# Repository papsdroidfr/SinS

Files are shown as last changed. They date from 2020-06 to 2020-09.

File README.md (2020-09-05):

# SinS
Dans le cadre du concours du #ChallengeDesMakers2020, notre équipe #OuiAreSins composée de François de https://www.framboise314.fr/, Frédéric de https://garatronic.fr/index.php/fr/, Dominique de https://shop.mchobby.be/fr/ et moi même Olivier de https://www.papsdroid.fr/ nous réalisons un jeux de mémoire visuelle et auditive à base d'une PYBStick26, mais ne vous y trompez pas:  Sins Is Not Simon !

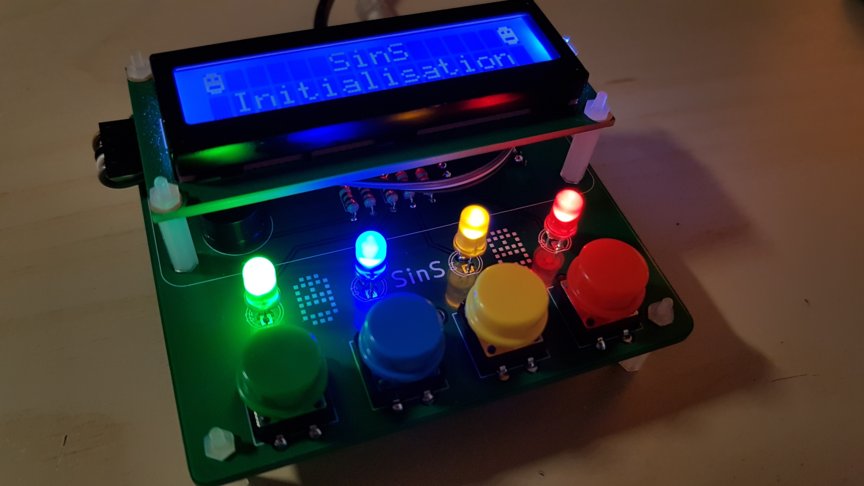
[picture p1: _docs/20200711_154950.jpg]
carte PCB


Il faut retrouver les clés de 10 coffres à trésors cachés dans un immense labyrinthe.

Dans chaque pièce où vous entrez, il y a 4 sorties de 4 couleurs distinctes. Vous avez un guide qui ouvre le chemin et vous montre les  3 prochaines portes à ouvrir pour trouver une première clé. Si vous réussissez, votre guide vous montre alors les 3 portes suivantes à ouvrir y compris les 3 premières déjà empruntées, et ainsi de suite... Le jeux se termine quand vous avez rapporté les 10 clés, ou bien quand vous vous trompez et êtes perdu dans le labyrinthe.

Vous pouvez jouer à plusieurs pour trouver les 10 clés: organisez votre équipe pour retenir le bon ordre d'ouverture des portes.

## matériel nécessaire
* 1 PYBStick26 avec ses deux barettes femelles 13pins soudées.
* 4 leds 5mm (Verte, Bleue, Jaune, Rouge)
* 4 résistances 220 ohms (pour les leds)
* 1 résistance 330 ohms (pour le buzzer), sinon 220 ohms sera aussi valable.
* 1 diode de redressement 1N4148 (optionel, le prototype fonctionne sans: c'est une diode de roue libre pour protéger le buzzer)
* 1 petit buzzer passif (attention à bien prendre un passif)
* 4 boutons poussoirs (6mm pour une breadboard, ou 12mm avec capuchons colorés ronds vert, bleu, jaune et rouge pour le circuit imprimé)
* 1 écran LCD 1602 avec backpack I2C
* 1 nappe souple femelle/femelle 4 pins, pour connecter le LCD au circuit.
* 1 connecteur pin header coudé 4 pins mâles 2.54mm, pour relier le LCD (impéartivement coudé pour le circuit imprimé)

Si vous comptez souder les composants sur le circuit imprimé proposé:
* 1 circuit imprimé, à faire fabriquer à partir des fichier GERBER_SINS.zip fournis.
* 1 alimentation 5V DC avec Jack femelle, 1A est suffisant 
* 1 diode Shotky SB560 (elle protège l'alimentation externe 5V quand l'USB est connectée)
* 1 connecteur Barrel JackDC mâle, 3 points de soudure
* 2 pin header mâle 13 pins 2.54mm à souder (pour y connecter la PYBStick)
* quelques entretoises M2.5 (ou M2 aussi ça passera): 8*M/F 15mm + 6 écrous + 2 vis

Le lien avec le tutoriel de montage sera bientôt ajouté sur ce dépôt.

## boîtier imprimé 3D 

François nous a réalisé un boîtier sur mesure à imprimer en 3D.
Le [lien avec les sources](https://ouiaremakers.com/posts/tutoriel-diy-un-boitier-en-impression-3d-pour-le-projet-ouiaresins)

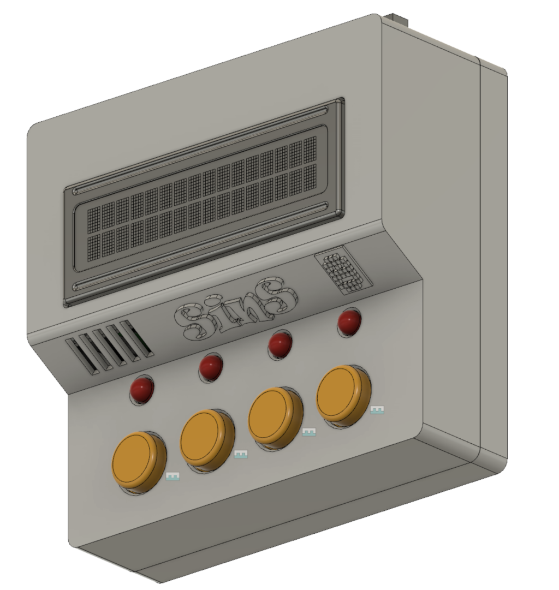
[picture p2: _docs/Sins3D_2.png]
boiter3D


## prototypage sur breadboard

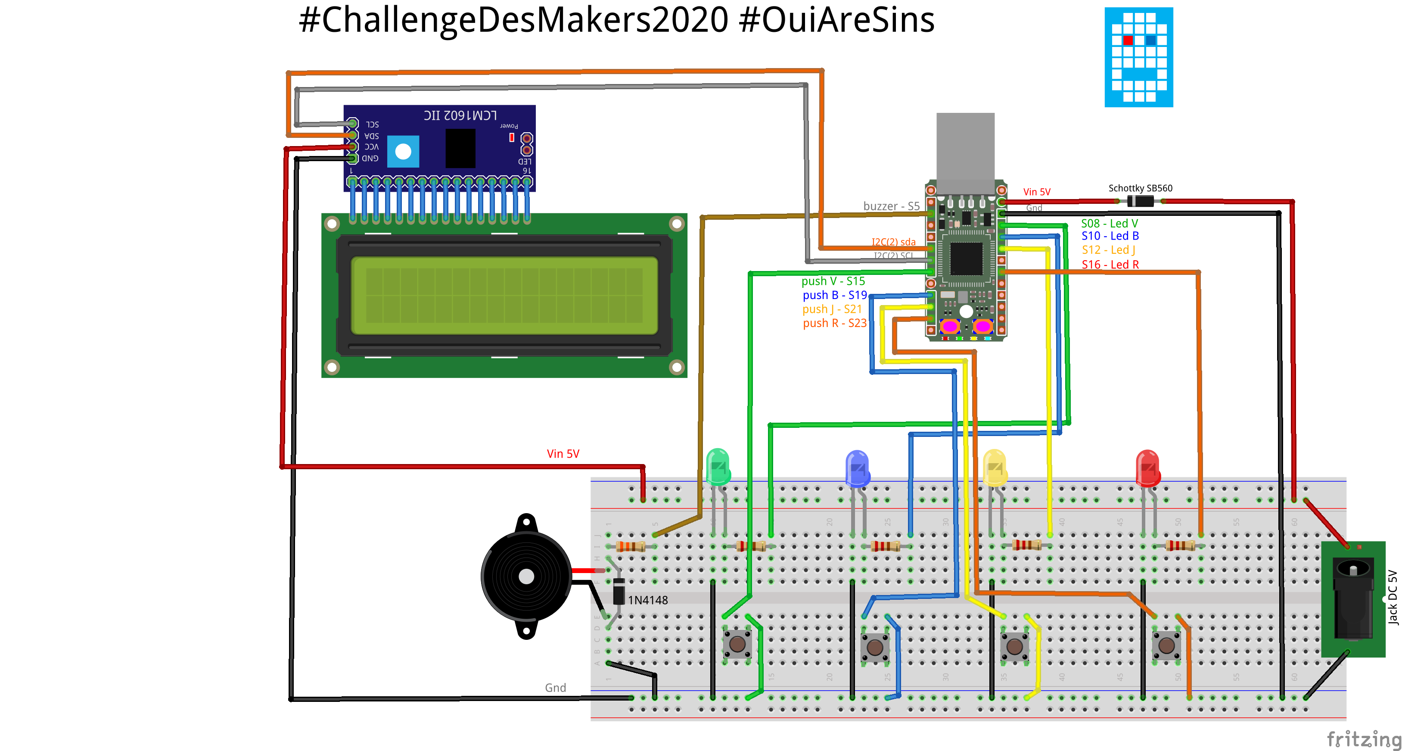
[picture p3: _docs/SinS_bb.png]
prototype breadbaord


## scripts micropython à installer sur la PYBStick
Dans le répertoire PYBFLASH qui s'affiche à l'ordinateur lors du branchement de la PYBStick26 sur un port USB, déposez tous les fichiers Micropython ci-dessous:
* buttons.py : gestion du rack de boutons poussoirs
* buzzer.py  : gestion du buzzer
* lcd.py     : gestion du LCD
* lcd2ic.py  : conçu par [MC Hobby](https://github.com/mchobby/pyboard-driver/tree/master/PYBStick): gestion du LCD via I2C de la PYBStick
* leds.py    : gestion du rack de leds
* main.py    : script principaldu jeux
* pwm.py     : conçu par [MC Hobby](https://github.com/mchobby/pyboard-driver/tree/master/PYBStick) : gestion des sorties PWM de la PYBStick

## synoptique du jeux
Un message d'accueil avec musique apparait, ainsi qu'une petite animation colorée des leds.

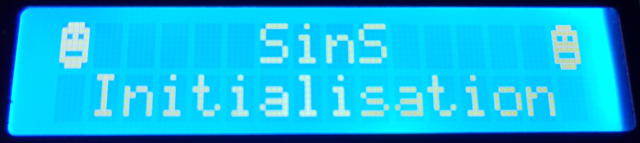
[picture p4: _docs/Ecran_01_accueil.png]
intro


Le joueur est ensuite invité à choisir un mode de jeux:
* __Vert__ : facile. De nouvelles séquences de 3 portes à ouvrir sont rajoutées sans modifier les précédentes. Chaque porte est associée à un son.
* __Bleu__ : moyen, idem que le mode vert mais sans les sons
* __Jaune__: difficile. Dans ce mode, la séquence de portes à ouvrir est réinitialisée au hasard depuis le début, avec les sons activés.
* __Rouge__: expert. Idem mode Jaune mais sans les sons.

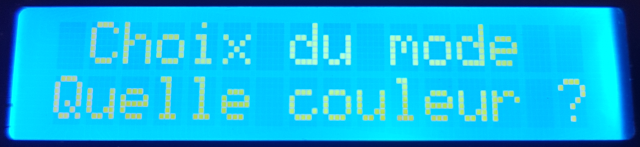
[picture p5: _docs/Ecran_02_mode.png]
choix mode


Le mode choisi est confirmé sur l'écran LCD

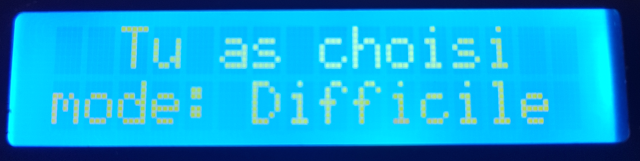
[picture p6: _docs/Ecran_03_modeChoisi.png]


Le joueur est alors invité à :
* observer la séquence de 3 portes (avec ou sans son, selon le mode choisi) à ouvrir, indiquée par le guide
* reproduire la même séquence à l'aide du rack de boutons poussoir

S'il gagne: la led verte va clignoter 3 fois, une clé est trouvée, et si le record du mode est battu il est aussi mis à jour.

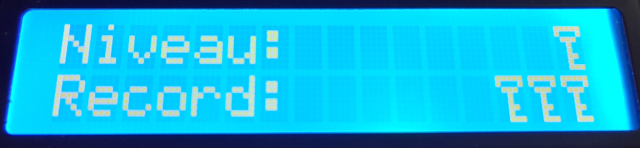
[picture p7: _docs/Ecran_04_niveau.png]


S'il se trompe, vous êtes perdu dans le labyrinthe de la PybStick! Une musique de la loose est jouée, la led rouge clignote 3 fois, et un message est indiqué sur l'écran.  Le jeux retourne alors sur l'écran de choix du mode.

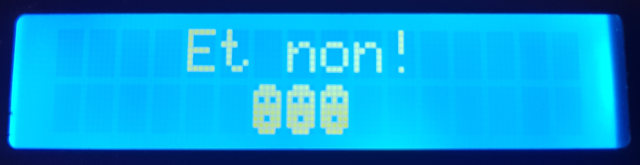
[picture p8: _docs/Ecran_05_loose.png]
loose


Si vous avez trouvé les 10 clés: bravo et respect !

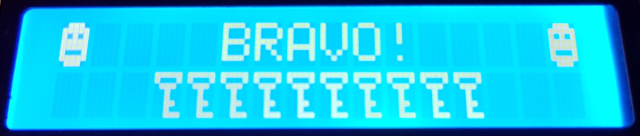
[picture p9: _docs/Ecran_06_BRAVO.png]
bravo


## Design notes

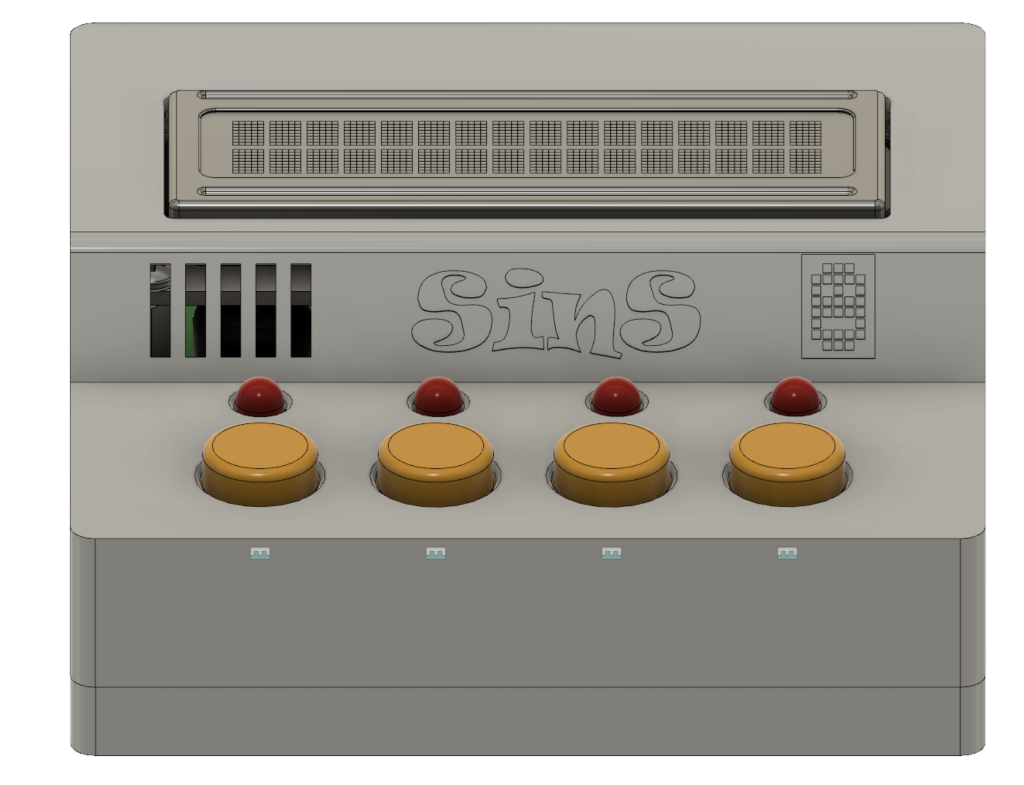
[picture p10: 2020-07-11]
_docs/Sins3D_1.png

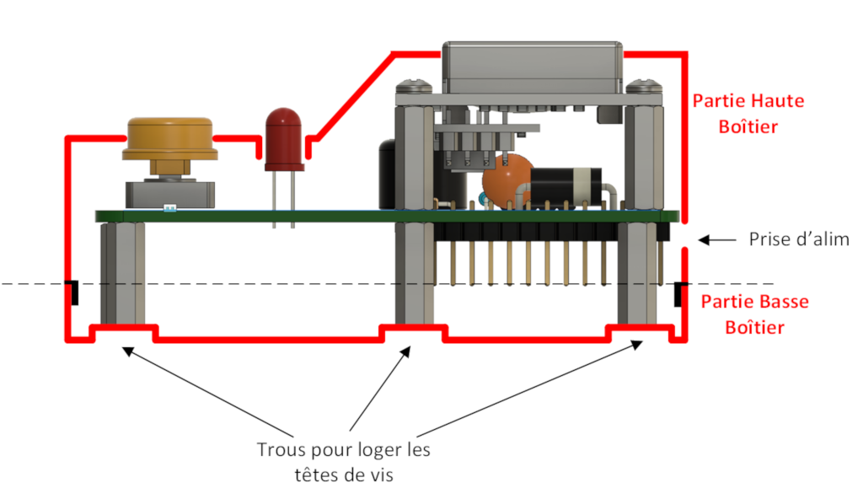
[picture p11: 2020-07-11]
_docs/Sins3D_5.png

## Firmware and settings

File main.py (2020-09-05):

#################################################################
#
# Auteur : papsdroid - https://www.papsdroid.fr
# Version: Août 2020
# script MicoPython principal du jeux SinS sur PYBStick26
#
################################################################"

from leds import RackLeds
from lcd import Lcd
from buzzer import Buzz
from buttons import RackButtons
from random import randint, seed
import time, os, utime

class Jeux_sins():
    """ classe gestion du jeux  """
    def __init__(self):
        """ constructeur """
        print ('Démarrage jeux ... ')
        self.lcd = Lcd()                # affichage LCD du jeux
        self.lcd.write_char('robot_ok', pos=(0,0) )
        self.lcd.msg_centre('SinS', 'Initialisation')
        self.lcd.write_char('robot_ok', pos=(15,0) )
        self.buzzer=Buzz()              # buzzer du jeux
        self.rackleds=RackLeds()        # rack de leds
        self.rackbuttons=RackButtons(self.rackleds, self.buzzer)  # rack de boutons
        self.color = ['V','B','J','R']  # couleur du jeux
        self.dic_color = {'V':0, 'B':1, 'J':2, 'R':3}
        self.file_scores = '/flash/scores.txt' # fichier des records
        self.scores = self.read_scores() # dictionnaire des record
        self.total_keys=10               # nb_clés à trouver   

        #mode de difficulté du jeux
        self.dic_mode = {
            'V': ['Vert',  'Facile']    ,
            'B': ['Bleu',  'Moyen']     ,
            'J': ['Jaune', 'Difficile'] ,
            'R': ['Rouge', 'Expert']    , 
            }
        self.mode = 'V'

        self.nb_portes=3              # nb de portes par niveau à ouvrir
        self.niveau = self.nb_portes  # nb de leds dans la séquence en cours
        self.init_seq()               # initialise séquences

    def init_seq(self):
        """ réinitialise les séquences à vide"""
        self.seq_led_droid = []
        self.seq_led_joueur = []
        #seed(randint(0,32000))  #initialize random number generator
        t=utime.localtime()         #format (y,m,d,h,m,s,ss,sss)
        s = t[3]*3600+t[4]*60+t[5] # conversion hh:mn:ss en secondes
        seed(s%2048)               # initialise table random non reproductibles 

    def add_seq(self):
        """ ajoute une séquence de nb_portes aléatoires au jeux"""
        for _ in range(self.nb_portes):
            self.seq_led_droid.append(self.color[randint(0,3)])
        
            
    def nouvelle_seq(self):
        """ détermine la nouvelle séquence de couleurs à trouver"""
        self.seq_led_joueur = []    # remise à zéro de la séquence du joueur
        if self.mode in ['J','R']:  # séquences aléatoires depuis le début
            self.seq_led_droid = []
            for n in range(self.niveau//self.nb_portes):
                self.add_seq()
        else:  # sinon on ajoute nb_portes couleurs au hasard
            self.add_seq()
    
    def add_sequence_joueur(self, color):
        """ ajoute la couleur jouée par le joueur"""
        self.seq_led_joueur.append(color)
        
    def read_scores(self):
        """ retourne le dictionaires des records à battre par mode V,B,J,R"""
        dic_scores = {'V':0, 'B':0, 'J':0, 'R':0} #scores par niveaux
        try:
            with open(self.file_scores, 'r') as f:
                for line in f.readlines():
                    l=line.strip()
                    mode,score = l[0], int(l[2:])
                    dic_scores[mode]=score
        except: #création du fichier score.txt s'il n'existe pas
            print('création fichier des scores')
            self.write_scores(dic_scores)
        print('record à battre par mode:', dic_scores)
        return dic_scores           
   
    def write_scores(self, scores):
        """ sauvegarde des record à battre"""
        with open(self.file_scores , 'w') as f:
            f.write('V:' + str(scores['V']) + '\n')
            f.write('B:' + str(scores['B']) + '\n')
            f.write('J:' + str(scores['J']) + '\n')
            f.write('R:' + str(scores['R']) + '\n')
    
    def loop(self):
        """ boucle principale du jeux"""
        while True :
            #initialisations
            self.init_seq()            
            self.niveau=self.nb_portes 
            self.lcd.clear()
            self.rackbuttons.desactivate_buzzer()
            self.lcd.msg_centre('Choix du mode', 'Quelle couleur ?' )
            
            # choix du mode de jeux
            self.rackbuttons.pressed = False
            while not(self.rackbuttons.pressed): #attente appui sur un bouton du rack
                time.sleep(0.2)
            self.mode = self.rackbuttons.button_pressed
            self.lcd.clear()
            self.lcd.msg_centre('Tu as choisi', 'mode: '+self.dic_mode[self.mode][1] )
            if self.mode in ['V','J']:
                self.rackbuttons.activate_buzzer() #buzzer activé uniquement pour les modes V et J
            time.sleep(2)
            self.lcd.clear()

            #boucle de jeux tant que le joueur trouve la bonne séquence
            continuer = True
            while (continuer):
                #création d'une nouvelle séquence à trouver
                self.nouvelle_seq()    
                #self.lcd.msg('Niveau:'+str(self.niveau), 'Record:'+ str(self.scores[self.mode]))
                self.lcd.msg('Niveau:', 'Record:')
                self.lcd.write_key(self.niveau//self.nb_portes, 0) # niveau
                self.lcd.write_key(self.scores[self.mode], 1)      # record du mode joué
                time.sleep(1)

                #affichage de la séquence à trouver
                for rang, color in enumerate(self.seq_led_droid):
                    self.rackleds.get_led(color).smooth_on()  # led allumée
                    if self.mode in ['V','J']:
                        self.buzzer.buzzId(color)       # son correspondant à la couleur uniquement pour les modes V et J
                    time.sleep(0.5)                     # temps d'attente en 2 leds
                    self.buzzer.mute()                  # buzzer mute
                    self.rackleds.get_led(color).smooth_off()  # led éteinte
                    time.sleep(0.5)                            # temps d'attente
                    if (rang+1)%self.nb_portes == 0:     # attente supplémentaires entre 2 séries de nb_portes
                        time.sleep(0.3)
                        
                #mémorisation séquence du joueur
                #print('à toi de jouer')
                self.rackbuttons.pressed = False
                for n in range(self.niveau):
                    #attente qu'un bouton du rack de boutons soit pressée
                    while not(self.rackbuttons.pressed):
                        time.sleep(0.2)
                    self.add_sequence_joueur(self.rackbuttons.button_pressed)
                    self.rackbuttons.pressed = False
                #print('Voici ton jeu: ', self.jeux.seq_led_joueur)
                #comparaison des listes
                self.rackbuttons.pressed = True #empêche la saisie sur une touche
                time.sleep(1)
                if (self.seq_led_joueur == self.seq_led_droid):
                    #print('Bien joué! niveau suivant')
                    self.rackleds.win()   #animation gagné
                    if (self.scores[self.mode] < self.niveau//self.nb_portes): # le record du mode est battu
                        self.scores[self.mode]=self.niveau//self.nb_portes     # maj du dictionnaire des records
                        self.write_scores(self.scores)          # enregistrement des records
                    if self.niveau == self.total_keys*self.nb_portes:
                        # toutes les clés sont trouvées
                        self.buzzer.welcome_sound()
                        self.lcd.clear()
                        self.lcd.msg_centre('BRAVO!')
                        self.lcd.write_char('robot_ok', pos=(0,0) )
                        self.lcd.write_char('robot_ok', pos=(15,0) )
                        for n in range(10):
                            self.lcd.write_char('key', pos=(3+n,1) )
                            time.sleep(0.3)
                        time.sleep(2)
                        continuer = False
                    else:
                        self.niveau += self.nb_portes
                else:
                    #print('Perdu!')
                    self.lcd.clear()
                    self.lcd.msg_centre('Et non!')
                    for l in range(6,9):
                        self.lcd.write_char('robot_ko', pos=(l,1))
                    self.buzzer.loose_sound()
                    self.rackleds.loose()    # animation perdu
                    time.sleep(1)
                    continuer = False

#script du jeux
#----------------------------------------------
jeux=Jeux_sins()
jeux.loop()

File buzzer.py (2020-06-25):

#################################################################
#
# Auteur : papsdroid - https://www.papsdroid.fr
# Version: Juin 2020
# Classe gestion du Buzzer du jeux sins sur PYBStick26
#
################################################################"

from machine import Pin
from pyb import Timer
from time import sleep

class Buzz():
    def __init__(self):
        """ constructeur, par défaut buzzerOn=False: non activé"""
        self.level=25        # niveau sonnore 0 (off) à 100 (max)
        self.freq_lam7 = [440, 523, 659, 784] #les bluesman vont reconnaître un accord de Lam7
        self.dic_freq={ 'V': 440, # fréquence ledG = La
                        'B': 523, # fréquence ledB = Do
                        'J': 659, # fréquence ledY = Mi
                        'R': 784  # fréquence ledR = Sol
                       }
        self.pin='S5'       # buzzer commandé par pin s5: Timer n°4, channel n°3 
        self.timer = Timer(4, freq=self.dic_freq['V'])
        self.channel = self.timer.channel(3,Timer.PWM, pin=Pin(self.pin))
        self.mute()
        self.welcome_sound()
        
    def mute(self):
        """ arrête le buzzer"""
        self.channel.pulse_width_percent(0)

    def play(self):
        """ active le buzzer, volume de 0 à 100"""
        self.channel.pulse_width_percent(self.level%101)
        
    def chg_freq(self, freq=500):
        """ modifie la fréquence du buzzer pour changer de note
        Table des fréquences par note/octave:
             0       1      2      3      4      5      6      7      8      9
        do   32.703  65.406 130.81 261.63 523.25 1046.5 2093.  4186.  8372.  16744.
        do#  34.648  69.296 138.59 277.18 554.37 1108.7 2217.5 4434.9 8869.8 17740.
        ré   36.708  73.416 146.83 293.66 587.33 1174.7 2349.3 4698.6 9397.3 18795.
        ré#  38.891  77.782 155.56 311.13 622.25 1244.5 2489.  4978.  9956.1 19912.
        mi   41.203  82.407 164.81 329.63 659.26 1318.5 2637.  5274.  10548. 21096.
        fa   43.654  87.307 174.61 349.23 698.46 1396.9 2793.8 5587.7 11175. 22351.
        fa#  46.249  92.499 185.   369.99 739.99 1480.  2960.  5919.9 11840. 23680.
        sol  48.999  97.999 196.   392.   783.99 1568.  3136.  6271.9 12544. 25088.
        sol# 51.913  103.83 207.65 415.3  830.61 1661.2 3322.4 6644.9 13290. 26580.
        la   55.     110.   220.   440.   880.   1760.  3520.  7040.  14080. 28160.
        la#  58.27   116.54 233.08 466.16 932.33 1864.7 3729.3 7458.6 14917. 29834.
        si   61.735  123.47 246.94 493.88 987.77 1975.5 3951.1 7902.1 15804. 31609.
        """
        self.timer.freq(freq)
            
    def buzzId(self, color):
        """fait sonner le buzzer avec une fréquence correspond à color
           color dans la liste ['green', 'blue','yellow', 'red']
        """
        self.chg_freq(self.dic_freq[color]) # modifie la fréquence du timer
        self.play()                         # active le son du buzzer

    def welcome_sound(self):
        """ joue un accord de Lam7"""    
        for freq in self.freq_lam7:
            self.chg_freq(freq)
            self.play()
            sleep(0.1)
        self.mute()

    def loose_sound(self):
        """ joue un accord de Lam7 à l'envers"""       
        for freq in self.freq_lam7[::-1]:
            self.chg_freq(freq)
            self.play()
            sleep(0.08)
        self.mute()
            
